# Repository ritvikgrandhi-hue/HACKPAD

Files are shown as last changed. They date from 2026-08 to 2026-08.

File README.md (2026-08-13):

# NINJAPAD
A macropad inspired by Ninjago with a EC11 rotary encoder, 0.91 in OLED display, and a 3x3 matrix of keys. 

## CAD DESIGN:


The final result of the CAD was an enclosure with 2 layers, where the bottom one holds the PCB in place while the top layer covers everything else. To be able to print the gold/yellow parts, I made each one a separate body to be able to 3D print it effectively. Done in Fusion 360.

## SCHEMATIC:


(Sorry for the overlapping labels!) No errors with DRC(for PCB), used a socket symbol for the OLED display and yeah. Done in KiCad.

## PCB:


This was the second longest thing to do. It took so many revisions to fix. For example, I accidentally put the parts too close together, then i forgot to add mounting holes, and had to keep it within the 100x100 size limit. Done in KiCad.

## HOW CASE GOES TOGETHER:


Two plates, glue the gold components on the top plate, put the pcb on the spacers of the bottom plate, and put an M3x16mm screw through it. You'll have to screw directly through the plastic spacers, as I didn't include heatset inserts.

## BOM:

- 1 Seeed XIAO RP2040(with header pins)
- 9x through-hole 1N4148 Diodes
- 9x MX-Style switches
- 1x EC11 Rotary encoders
- 1x 0.91 inch OLED display
- 9x DSA keycaps
- 4x M3x16mm screws
- Case
- PCB
- Soldering iron to put things together

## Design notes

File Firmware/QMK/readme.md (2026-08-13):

# ninjapad

ninjapad

*A short description of the keyboard/project*

* Keyboard Maintainer: [Ritvik Grandhi](https://github.com/ritvikgrandhi-hue)
* Hardware Supported: *The PCBs, controllers supported*
* Hardware Availability: *Links to where you can find this hardware*

Make example for this keyboard (after setting up your build environment):

    make ninjapad:default

Flashing example for this keyboard:

    make ninjapad:default:flash

See the [build environment setup](https://docs.qmk.fm/#/getting_started_build_tools) and the [make instructions](https://docs.qmk.fm/#/getting_started_make_guide) for more information. Brand new to QMK? Start with our [Complete Newbs Guide](https://docs.qmk.fm/#/newbs).

## Bootloader

Enter the bootloader in 3 ways:

* **Bootmagic reset**: Hold down the key at (0,0) in the matrix (usually the top left key or Escape) and plug in the keyboard
* **Physical reset button**: Briefly press the button on the back of the PCB - some may have pads you must short instead
* **Keycode in layout**: Press the key mapped to `QK_BOOT` if it is available

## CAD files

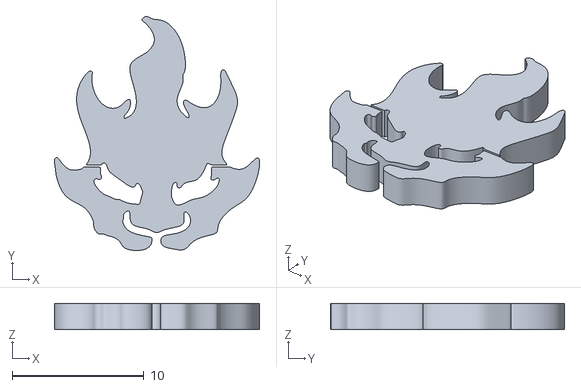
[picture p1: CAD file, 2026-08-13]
Production/STLS/Topkai(GOLD).stl
15.6 x 17.8 x 2.00

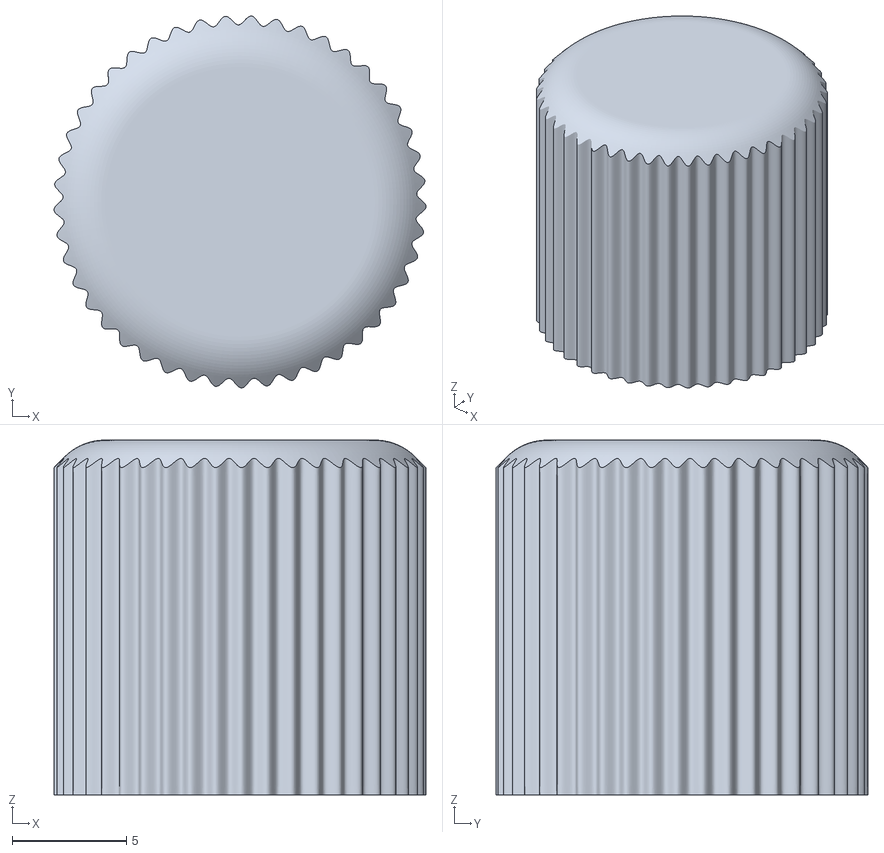
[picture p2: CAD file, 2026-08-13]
Production/STLS/EC11knob(BLACK).stl
16.3 x 16.2 x 15.5

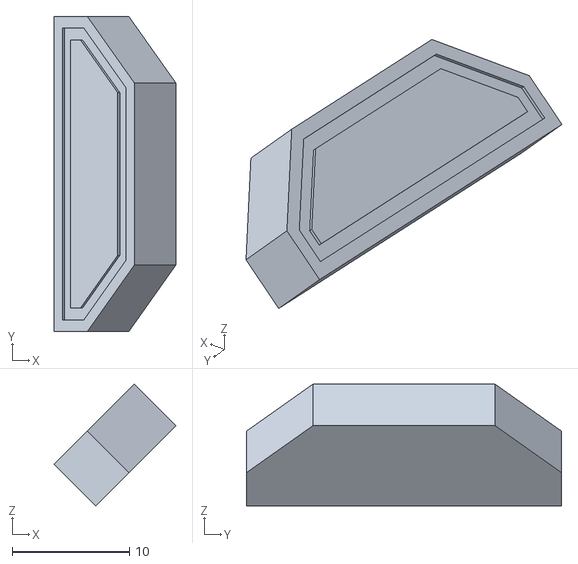
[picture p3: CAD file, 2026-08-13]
Production/STLS/Leftlabel(GOLD).stl
10.4 x 26.8 x 10.4

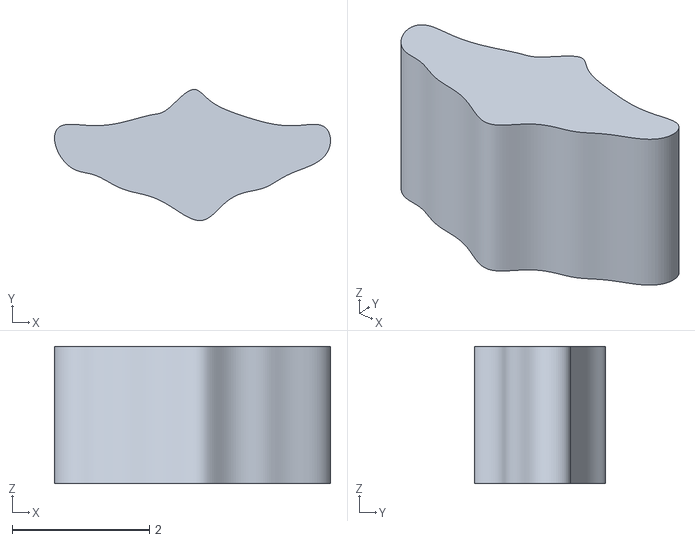
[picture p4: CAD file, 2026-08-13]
Production/STLS/Bottomkai(GOLD).stl
4.02 x 1.91 x 2.00

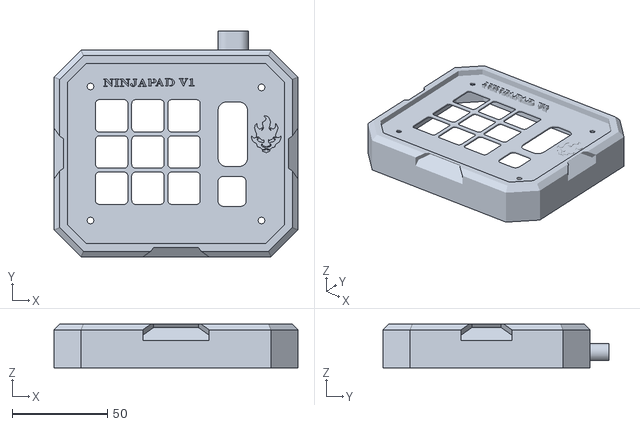
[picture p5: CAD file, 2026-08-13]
Production/STLS/TOPPLATE(RED).stl
128.4 x 118.9 x 23.0

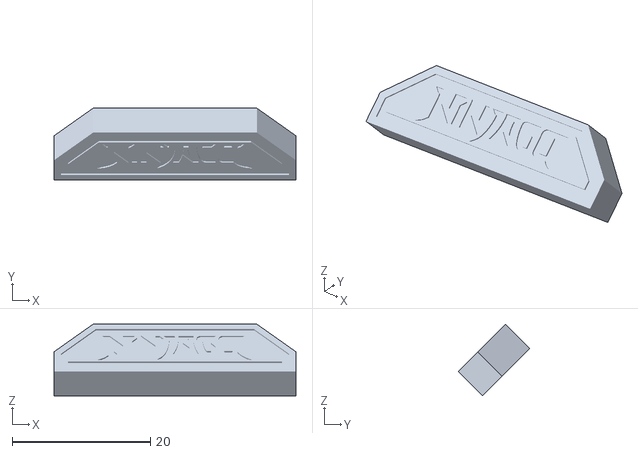
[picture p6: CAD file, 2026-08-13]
Production/STLS/Frontlabel(GOLD).stl
35.0 x 10.4 x 10.4

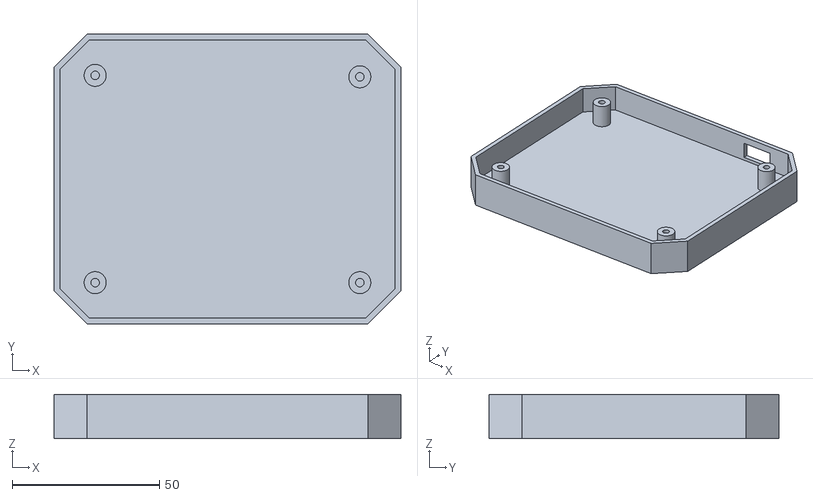
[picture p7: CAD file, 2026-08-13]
Production/STLS/BASEPLATE(GOLD).stl
118.0 x 98.5 x 15.0

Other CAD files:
Production/STLS/Rightlabel(GOLD).stl

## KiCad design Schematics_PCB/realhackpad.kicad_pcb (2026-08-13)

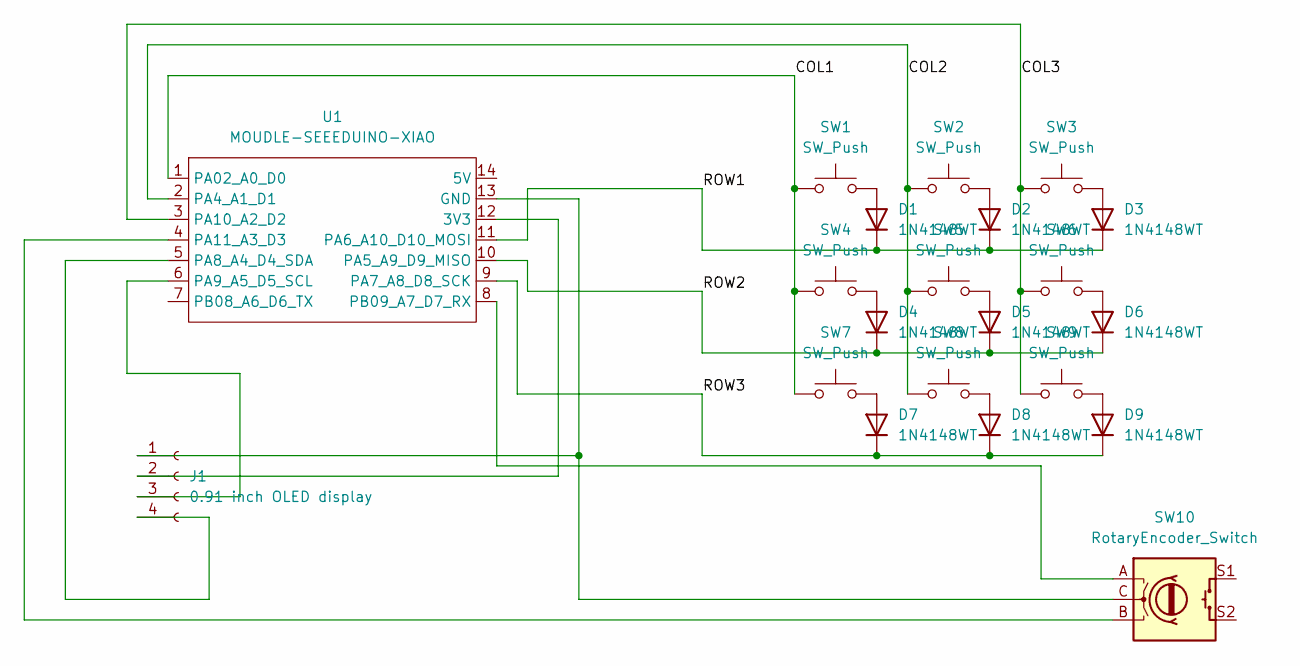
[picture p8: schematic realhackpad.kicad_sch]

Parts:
D1, D2, D3, D4, D5, D6, D7, D8, D9: 1N4148WT; D_SOD-523
J1: 0.91 inch OLED display; SSD1306-0.91-OLED-4pin-128x32
SW1, SW2, SW3, SW4, SW5, SW6, SW7, SW8, SW9: SW_Push; SW_Cherry_MX_1.00u_PCB
SW10: RotaryEncoder_Switch; RotaryEncoder_Alps_EC11E-Switch_Vertical_H20mm
U1: MOUDLE-SEEEDUINO-XIAO; XIAO-Generic-Hybrid-14P-2.54-21X17.8MM

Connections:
/COL1: SW1.1, SW4.1, SW7.1, U1.1 (PA02_A0_D0)
/COL2: SW2.1, SW5.1, SW8.1, U1.2 (PA4_A1_D1)
/COL3: SW3.1, SW6.1, SW9.1, U1.3 (PA10_A2_D2)
/ROW1: D1.1 (K), D2.1 (K), D3.1 (K), U1.11 (PA6_A10_D10_MOSI)
/ROW2: D4.1 (K), D5.1 (K), D6.1 (K), U1.10 (PA5_A9_D9_MISO)
/ROW3: D7.1 (K), D8.1 (K), D9.1 (K), U1.9 (PA7_A8_D8_SCK)
unnamed: D1.2 (A), SW1.2
unnamed: D2.2 (A), SW2.2
unnamed: D3.2 (A), SW3.2
unnamed: D4.2 (A), SW4.2
unnamed: D5.2 (A), SW5.2
unnamed: D6.2 (A), SW6.2
unnamed: D7.2 (A), SW7.2
unnamed: D8.2 (A), SW8.2
unnamed: D9.2 (A), SW9.2
unnamed: J1.1 (GND), SW10.C, U1.13 (GND)
unnamed: J1.3 (SCL), U1.6 (PA9_A5_D5_SCL)
unnamed: J1.4 (SDA), U1.5 (PA8_A4_D4_SDA)
unnamed: J1.2 (VCC), U1.12 (3V3)
unnamed: SW10.B, U1.4 (PA11_A3_D3)
unnamed: SW10.A, U1.8 (PB09_A7_D7_RX)

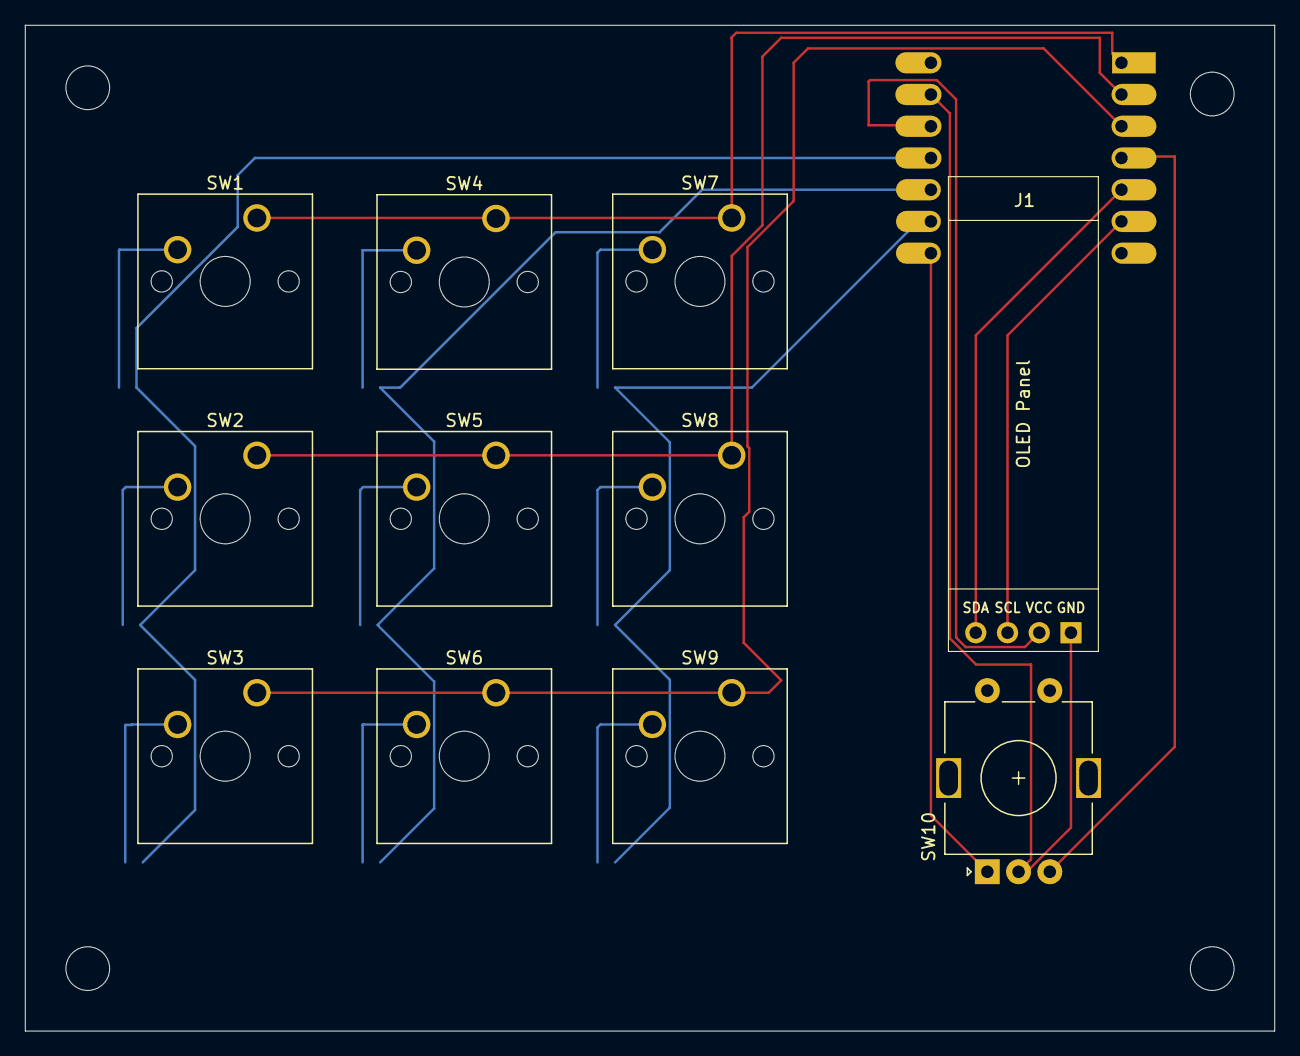
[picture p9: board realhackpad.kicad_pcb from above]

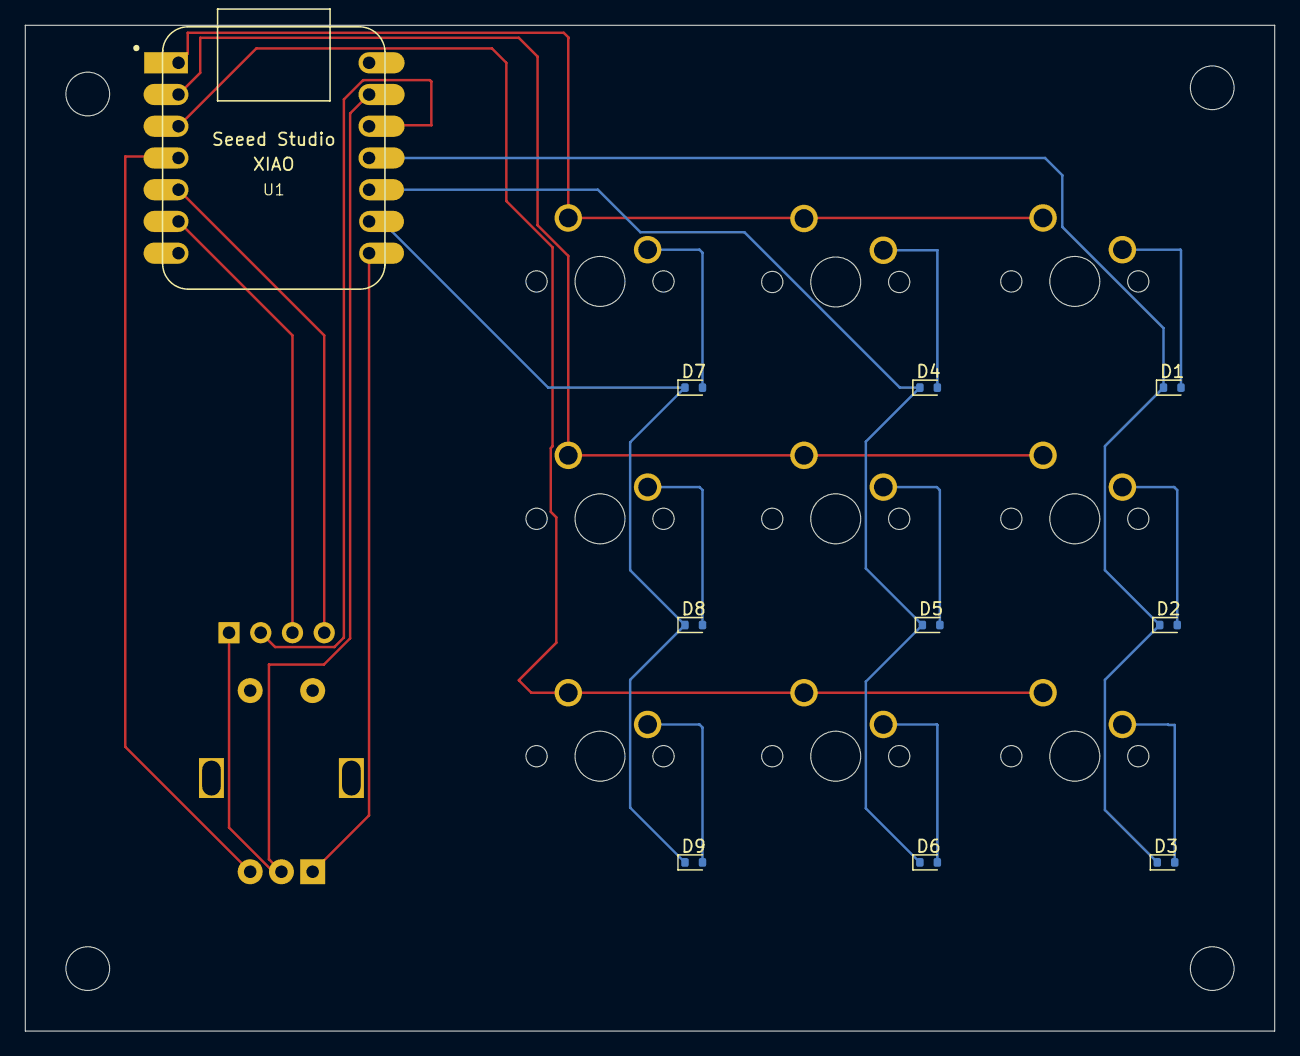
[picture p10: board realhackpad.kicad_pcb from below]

Board: 2 copper layers, 100.0 x 80.5 mm, 21 parts (10 on the bottom side), 21 nets.

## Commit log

2026-08-09 Add files via upload
    The sym files are for kicad symbols, and the rest is the pcb and schematic so far.
    [hackpad.kicad_pcb, hackpad.kicad_sch]
2026-08-10 Create CAD
2026-08-13 Revise README for Ninjapad project details
    Updated README to reflect project name and details for Ninjapad, including CAD design, schematic, PCB, assembly instructions, and BOM.
2026-08-13 production done
    [BASEPLATE(GOLD).stl, Bottomkai(GOLD).stl, EC11knob(BLACK).stl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]
